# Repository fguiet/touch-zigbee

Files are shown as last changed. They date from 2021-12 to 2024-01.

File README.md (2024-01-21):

#  Touch-Zigbee

## Forewords

This project aims at creating a ultra low powered capacitive XBee enabled touch button.

It can be used to replace mechanical on/off switch to turn on/off a lamp for instance.

Mecanical swich should be me removed and wire connected so that the lamp is always ON.

Less than 10 uA is required to make this stuff work :)

__My Use case :__

I have got a Hue lamp in my office. 

Hue lamp can be switch off and on thank to the Philips Hue API.

So I am gonna replace the mecanical on/off swith by the Touch-Zigbee switch.

Here is the workflow:

Touch-Zigbee capacitive switch sends a message to a zigbee reveiver plugged in a Rapsberry.

A nodered flow will listen to the ZigBee messages and call the Philips Hue API to turn the Hue lamp on and off.

Obviously, the API or Nodered communicates with Home Assitant so I can see the Philips Hue Lamp status.

Moreover, I can programm some scenes when not at home to simulate that somebody is at home.

## Documentation

Here is some notes I took when I realized this project : [Project Notes](documentation/touch-zigbee.md)

## Illustrations

* Bare PCB received from JLCPCB and realized with KiCAD 5.1.12

Diameter : only 5 cm (can be insert in a standard French mecanical on/off switch case)

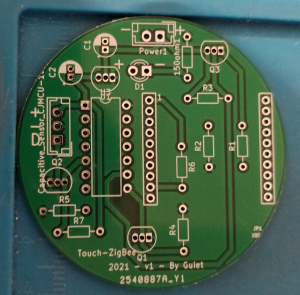
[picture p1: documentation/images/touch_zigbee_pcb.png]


* Assembled PCB 

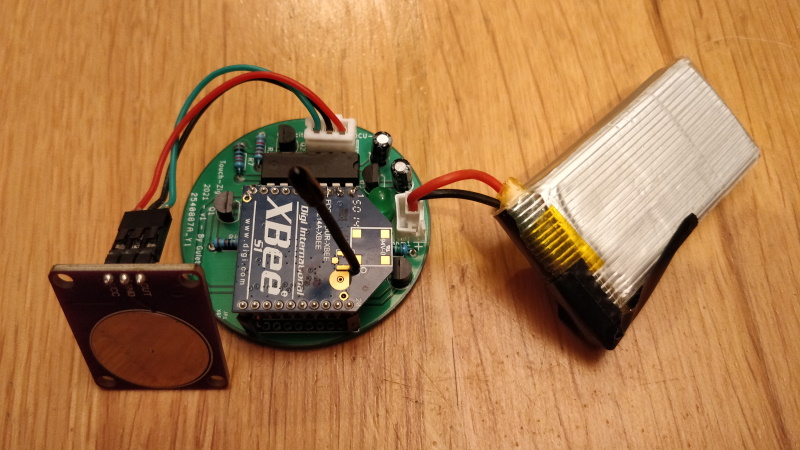
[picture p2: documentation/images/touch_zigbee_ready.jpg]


* Testing XBee communication with XCTU

NB : Version 2.0.0 of this project use XBee API Mode 2 (as you can see of the picture below I was using transparent mode before (AT))

Battery voltage can be read and send :) Nice

A led is blinking when the capacitive sensor is touched :)

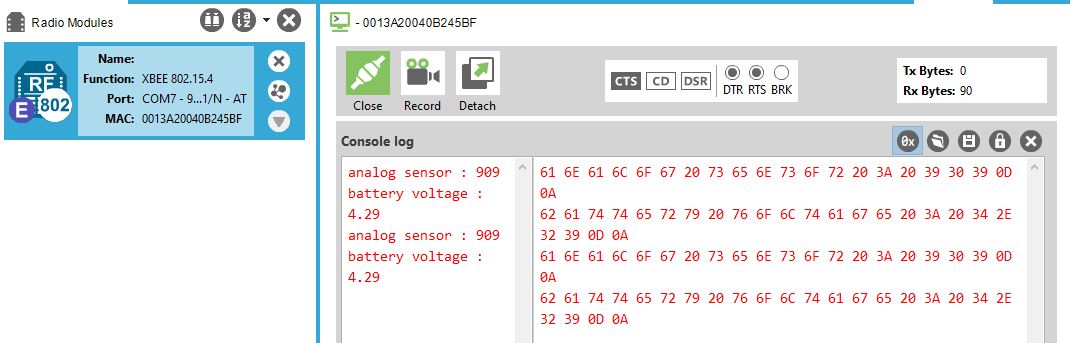
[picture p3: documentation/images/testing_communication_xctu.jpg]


* Wall plug design in FreeCAD

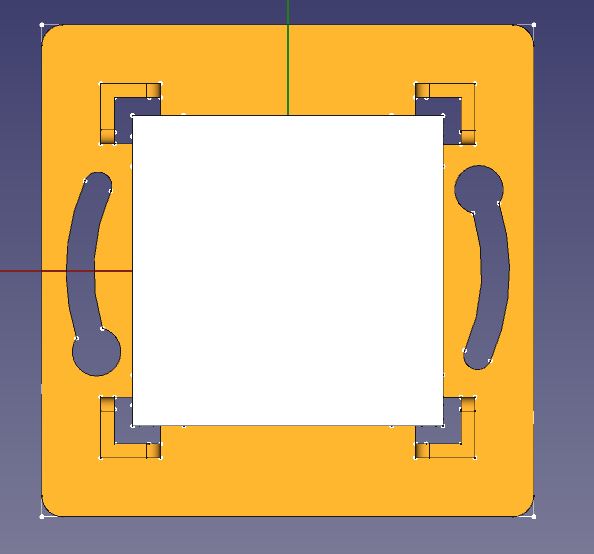
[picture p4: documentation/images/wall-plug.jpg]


* 3D Printing wallplug (not the last version)

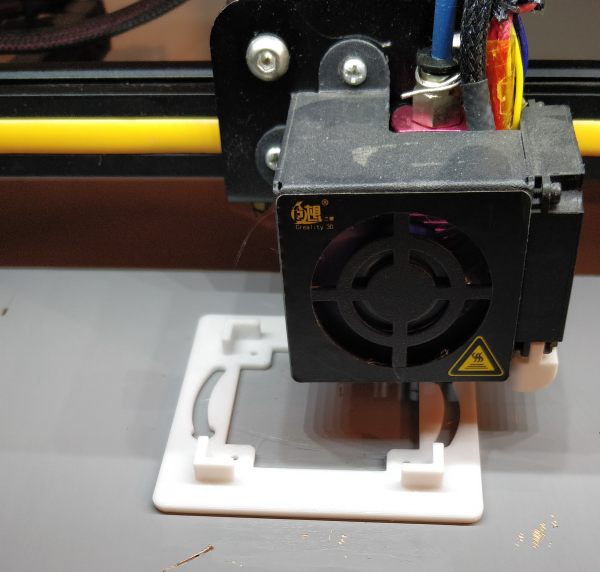
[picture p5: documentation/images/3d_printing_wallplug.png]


* Assembling the whole stuff (I do not have the XBee pin header at you can see, it is coming from China)

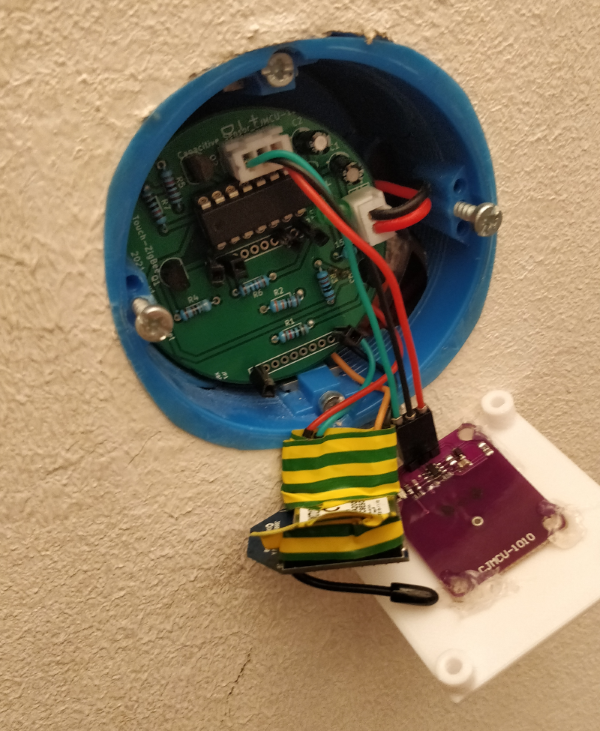
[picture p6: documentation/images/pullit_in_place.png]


* Everything in place (last version remove the little gaps)

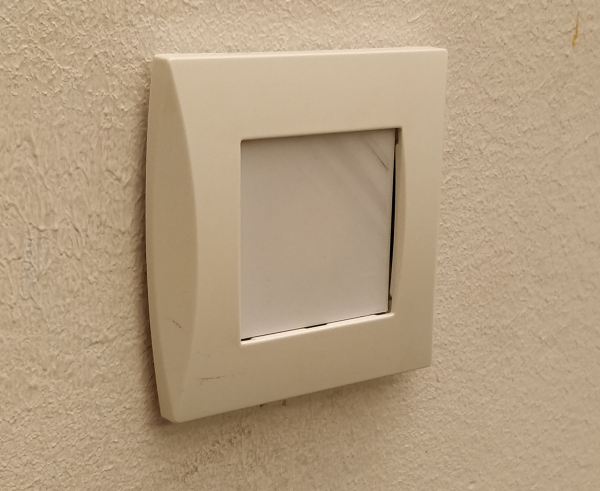
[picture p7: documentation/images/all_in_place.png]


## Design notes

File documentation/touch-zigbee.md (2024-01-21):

# Touch-Zigbee

## Consumption

* CMJMCU-1010 and 7333-LDO 

With tiny led that indicates power on is on

        Consumption : 1.2 mA (no touch)

        Consumption : 2.3 mA (touch + touch led indicator is on)

When tiny led with tiny led that indicates power on is removed

        Consumption : < 10uA (no touch)

        Consumption : around 1.2 mA (touch + touch led indicator is on)

* ATtiny 84 + green led and 150ohm reistor

        Consumption : 1.2 mA (green led off)

        Consumption : 8.5 mA (green led on)

* ATtiny 84 alone (sleep mode, no ADC)

        Consumption : 1.6uA

* ATtiny 84 + XBee (no sleep)

        Consumption : 52 mA

* ATtiny 84 + XBee (sleep)

        Consumption : around 4uA

* ATiny 84 (sleep mode) + XBee (sleepmode) + CMJMCU-1010

        Consumption : Peak at 20 uA when touching then less than 10 uA :)

## Configuring XBee S1 with XCTU v6.5.6

I am using old XBee S1

### XBee firmware update

Update the XBee firmware with last version using XCTU v6.5.6

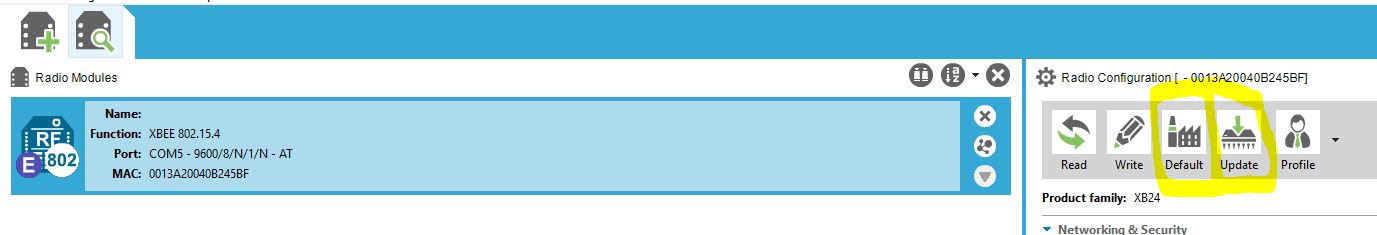
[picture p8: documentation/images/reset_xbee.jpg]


In my case as of 2021/11 :



To make the Xbee talks to each other just config them with the same Channel and PAN (Personnal Area Network ID). Messages will be broadcasted.



### XBee pinout

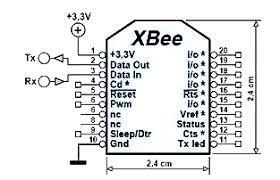
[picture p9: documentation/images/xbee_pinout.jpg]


### Sleep mode

To config the Xee to use the sleep mode, just change the sleep mode setting



Sleep mode will be control by pin 9, see <https://www.digi.com/resources/documentation/Digidocs/90001456-13/reference/r_wk_sleep_mode.htm>

PIN 9 HIGH : Xbee sleeps
PIN 9 DOWN : Xbee awake

### API Mode 

2024/01/21 - Quite a big change. I am using Xbee API with escaped mode instead of transparent mode (AT). So know I can have more information (like RSSI) and be compatible with my other projects.



## Read battery voltage

https://gist.github.com/dwhacks/7208805

## Pull up / pull down

Quick reminder if pullup/pulldown : <https://arduino.developpez.com/cahiers-pratiques/resistance-pullup-pulldown/>

## Interrupt and power saving stuffwith ATtiny 85

See <https://forum.arduino.cc/t/attiny84-sleep-issues/199824/8>
See <http://www.gammon.com.au/power>
See <https://www.marcelpost.com/wiki/index.php/ATtiny84_ADC>

Extract from ATtiny datasheet p49.

²> 9.2 External Interrupts
> Note that recognition of falling or rising edge interrupts on INT0 requires the presence of an
> I/O clock, as described in “Clock Sources” on page 25.

## Add SoftSerial to the Arduino IDE

From 2024/01/21, I moved to XBee API Mode. 
Firmware is now 2.0.0.
I had a hard time making XBee API Mode to work.

The libray I used up to know : SoftwareSerial was not capable of working at more than 9600 bauds...it took quite a long time to understand this problem.

So I tried to use the following library [ATtinySerialOut](https://github.com/ArminJo/ATtinySerialOut). 

But I soon realiazed that this library was not working with the PIN 7 (PA6).

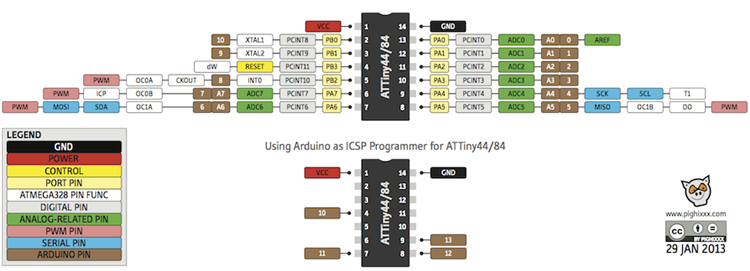
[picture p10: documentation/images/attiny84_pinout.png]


The only working pin was PB1 (PIN 3) or PB2 (PIN 5) at 38400 bauds.

This made me change the PCD Datasheet...I soldered a piece of wire to make it work for now...

To debug the serial port I used a serial to USB port adapter

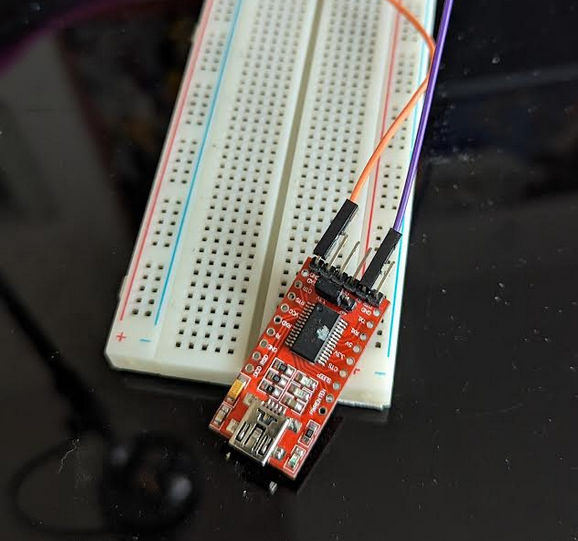
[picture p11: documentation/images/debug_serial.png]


GND to GND
PIN RX (serial adapter) to PA1 of ATtiny

Then I used `screen`

```bash
# Quit CTRL-A then :quit
screen /dev/ttyUSB0 38400
```

__Note below are deprecated from 2024/01/21 :__

I am using the SoftwareSerial that comes with the Arduino IDE : See <C:\Users\fguie\AppData\Local\Arduino15\packages\arduino\hardware\avr\1.8.3\libraries\SoftwareSerial>

It may be possible to use another one:

See : <https://github.com/shimniok/ATtinySoftSerial>

See <https://www.arduino.cc/en/guide/libraries>, Manual installation

1. Go to File, Preferences and get the sketchbook location
2. Copy the library to the libraries folder (in my case `C:\Users\fguie\Documents\Arduino\libraries`)

## Program the ATtiny XX (ATtiny 84 in my case) using Arduino IDE

See <https://github.com/damellis/attiny>
See <http://highlowtech.org/?p=1695>
See <http://highlowtech.org/?p=1706>

Arduino used as an ISP (In System Programmer)

1. Select the Arduino Uno Board, then upload ISP sketch to the Arduino
2. follow this wiring diagram : <https://www.instructables.com/Using-the-Arduino-Uno-to-program-ATTINY84-20PU/> or <https://42bots.com/tutorials/programming-attiny84-attiny44-with-arduino-uno/> (See image below)



Don't forget to set Programmer : Arduino As ISP and select the ATtiny 84 Board

To program:

VCC (3.3v ou 5V) <=> VCC (pin1)

GND <=> GND (pin14)

Arduino Pin 10 <=> RESET 

Arduino Pin 11 <=> pin7 (arduino pin 6)

Arduino Pin 12 <=> pin8 (arduino pin 5)

Arduino Pin 13 <=> pin9 (arduino pin 4)

## Kicad

__Schematic__

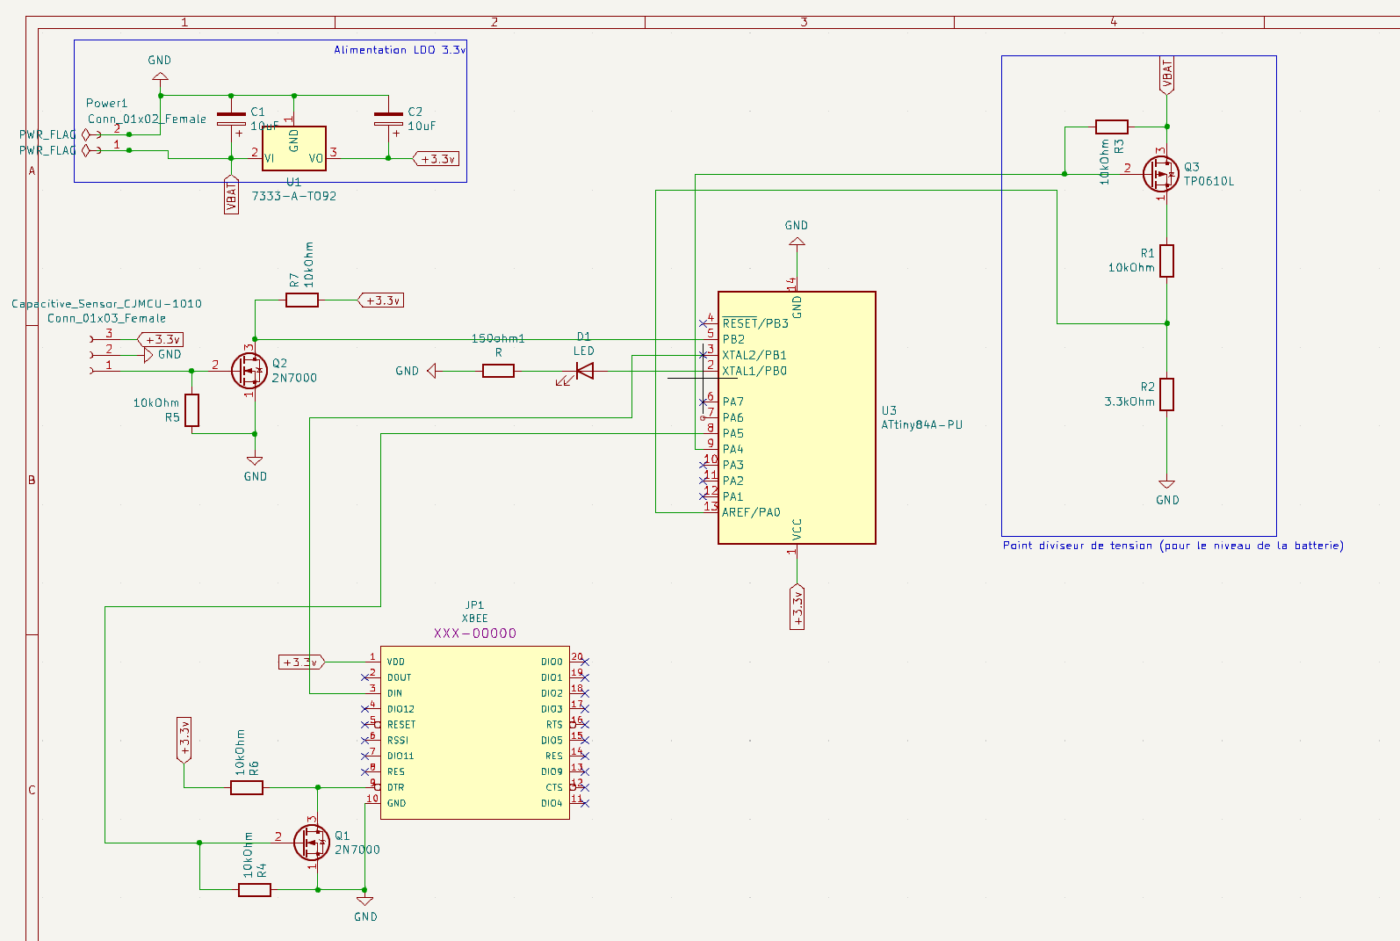
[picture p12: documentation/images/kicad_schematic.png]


Ce tuto : <https://www.youtube.com/watch?v=RpVIrzEUsIM&t=1837s>

__Grandes étapes__

1. Remplir le cartouche

Fichier, Ajustage page

2. Place all your components

Shortcut

M : Move
R : Rotate
Tab  : Pour bouger le composant avec les fils accrochés

3. Annotation de la schématique (pour numéroter les composants)

4. Assigner les empreintes des composants de la schématique

5. Génération de la net liste

6. Editeur de circuit imprimé et lecture de la net liste

7. Placement des composants

8. Couche Edge cut (contour de carte)

9. Routage

Couche F. Cu (Front en rouge couche du dessus)
Couche B. Cu (Front en vert couche du dessous)

Fichiers, Options CI, Classe d'Equipots, j'utilise 0.762 comme largeur de piste

Ne pas relier les GND, ca sera automatique avec le plan de masse

10 . Serigrafie avec couche Drawing User pour mettre les indications + - et autres

11 . Générer les fichiers Gerber, Fichier Tracer (ne pas oublier de générer le fichier de percage)

12 . Faire un Zip et envoyer sur JLCPCB par exemple

## References 

* [Communication XBee](https://www.redohm.fr/2015/03/communication-xbee/)
* [Configuration XBee](https://www.electro-info.ovh/configuration-d-un-module-XBEE-avec-XCTU)
* [Un programme qui ressemble a ce que je fais](https://github.com/cano64/ATTiny85-ATTiny84-BMP085-Arduino-Library-FastAltitude/issues/1)
* [How works a switch without neutral](https://www.youtube.com/watch?v=VNYcD7MEp4A)

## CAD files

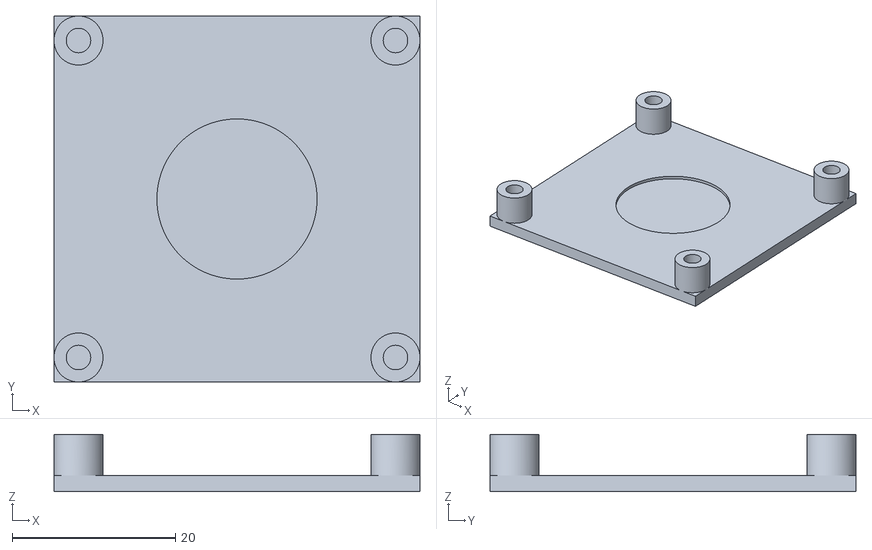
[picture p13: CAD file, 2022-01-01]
freecad/wallplug-wallplug-front-body.stl
44.8 x 44.8 x 7.00

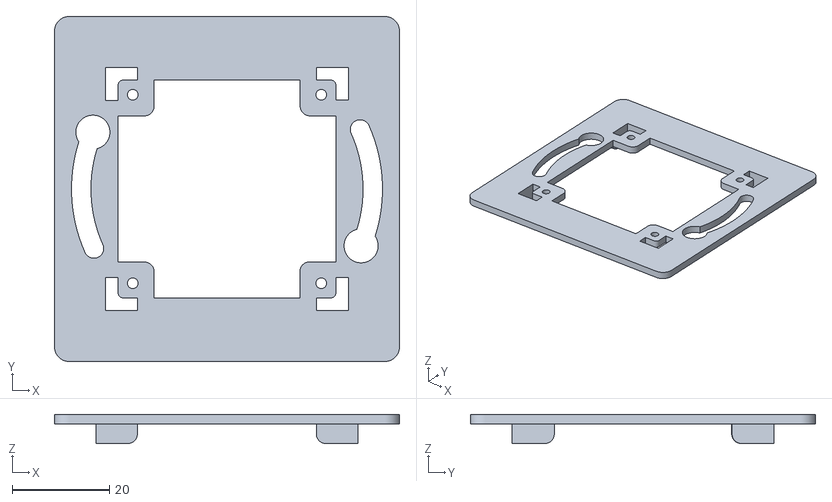
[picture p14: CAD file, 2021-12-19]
freecad/wallplug-wallplug-behind-body.stl
71.0 x 71.0 x 6.00

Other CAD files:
freecad/wallplug.FCStd

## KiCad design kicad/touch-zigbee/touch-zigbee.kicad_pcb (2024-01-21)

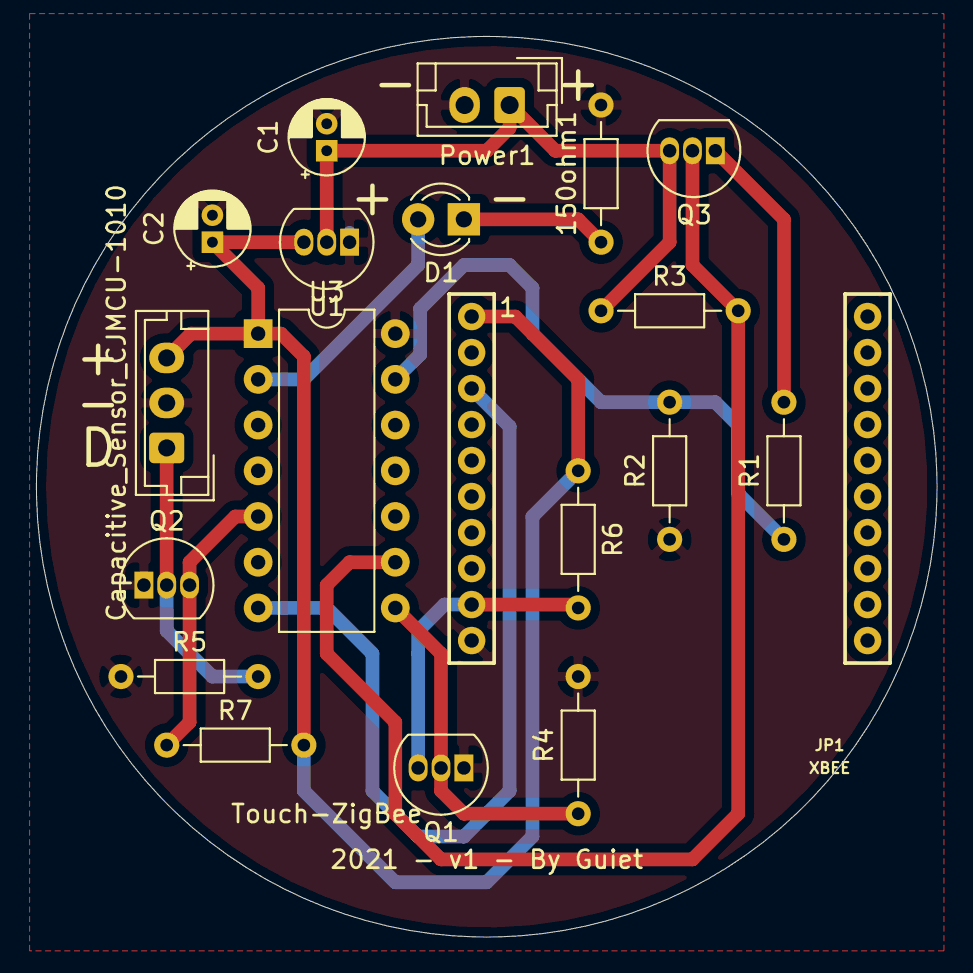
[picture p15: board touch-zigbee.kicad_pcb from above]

Board: 2 copper layers, 50.0 x 50.0 mm, 19 parts (0 on the bottom side), 13 nets.

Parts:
150ohm1: R; R_Axial_DIN0204_L3.6mm_D1.6mm_P7.62mm_Horizontal
C1, C2: 10uF; CP_Radial_D4.0mm_P1.50mm
Capacitive_Sensor_CJMCU-1010: Conn_01x03_Female; JST_EH_B3B-EH-A_1x03_P2.50mm_Vertical
D1: LED; LED_D3.0mm_IRBlack
JP1: XBEE
Power1: Conn_01x02_Female; JST_EH_B2B-EH-A_1x02_P2.50mm_Vertical
Q1, Q2: 2N7000; TO-92_Inline
Q3: TP0610L; TO-92L_Inline
R1, R3, R4, R5, R6, R7: 10kOhm; R_Axial_DIN0204_L3.6mm_D1.6mm_P7.62mm_Horizontal
R2: 3.3kOhm; R_Axial_DIN0204_L3.6mm_D1.6mm_P7.62mm_Horizontal
U1: 7333-A-TO92; TO-92_Inline
U3: ATtiny84A-PU; DIP-14_W7.62mm

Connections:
+3.3v: C2.1, Capacitive_Sensor_CJMCU-1010.3, JP1.1, R6.1, R7.2, U1.3, U3.1
GND: 150ohm1.2, C1.2, C2.2, Capacitive_Sensor_CJMCU-1010.2, JP1.10, Power1.2, Q1.1, Q2.1, R2.1, R4.2, R5.1, U1.1, U3.14
unnamed: 150ohm1.1, D1.1
unnamed: Capacitive_Sensor_CJMCU-1010.1, Q2.2, R5.2
unnamed: D1.2, U3.2
unnamed: JP1.3, U3.7
unnamed: JP1.9, Q1.3, R6.2
unnamed: Q1.2, R4.1, U3.8
unnamed: Q2.3, R7.1, U3.5
unnamed: Q3.1, R1.2
unnamed: Q3.2, R3.2, U3.9
unnamed: R1.1, R2.2, U3.13
VBAT: C1.1, Power1.1, Q3.3, R3.1, U1.2

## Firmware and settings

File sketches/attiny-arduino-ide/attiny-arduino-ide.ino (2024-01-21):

/*
 *  Touch-Zigbee project
 *  
 *  Description:
 *     
 *     This program uses interrupt to detect when the capacitive button is touched
 *     Then it wakes up the XBee and send a message
 *     The message is received on another XBee plugged in a Raspberry.
 *     A Nodered flow then toggle the Philipps Hue light bulb on and off depending on the current light bulb state.
 *     
 *     This is an ultra low power battery operated design. It consumes only 10uA when sleeping.
 *     
 *     More info here : https://github.com/fguiet/touch-zigbee
 *     
 *  Board used : Using board 'ATtinyX4' from platform in folder: C:\Users\fguie\AppData\Local\Arduino15\packages\attiny\hardware\avr\1.0.2   
 *               Using Arduino As ISP to program the ATtiny84
 *               Careful : Serial only work at Clock Internal 1Mhz (do not use Clock Internal 8Mhz)
 *     
 *
 *  History : 
 *     - 2021/12/19 - Creation date - Firware Version 1.0
 *     - 2024/01/21 - Replace use of SoftwareSerial library, use of ATtinySerialOut at 38400 bauds. 
 *                  - ATtinySerialOut consumes less memory and allow use of 38400 bauds. SoftwareSerial only works at 9600 bauds
 *                  - Change to XBee API Mode 2 instead of Transparent mode
 *                  - ATtinySerialOut must be connected to PIN PB1 = Physical PIN 3 otherwise it does not work (so PCB schematic has been changed as well)
 *                  - Firmware Version is now 2.0
 *  
 *  Version : 2.0
 *  
 */

#include <avr/sleep.h>

//Uncomment this line below if you want to use 38400 bauds instead of 115200 bauds
#define TINY_SERIAL_DO_NOT_USE_115200BAUD

//PIN PB1 = Physical PIN 3
#define TX_PIN 1

//Work only clock internal set to 1Mhz and with TX_PIN set to 2, baud is 38400 bauds
#include "ATtinySerialOut.hpp"  // Available as Arduino library "ATtinySerialOut"

// ATTIny84 
// Use Arduino Pin on the pinout 
const byte LED = 10;
const byte PIN_LINK_TO_INT_PIN=8;
const byte INT_PIN=0; //This is the interrupt number link to pin 8
const byte WAKE_XBEE=5;
const byte ADC_PIN=0; //Arduino pin 13
const byte ENABLE_BATTERY_V_READING=4;

//Hue light bulb
//Office = 2
const String SENSOR_ID="2";
const String FIRMWARE_VERSION="2.0.0";

const byte numReadings = 5;

// the setup routine runs once when you press reset:
void setup() {
  // Must be called once if pin is not set to output otherwise
  initTXPin();

  // initialize the digital pin as an output.
  pinMode(LED, OUTPUT); 
  pinMode(PIN_LINK_TO_INT_PIN, INPUT_PULLUP);  

  pinMode(ENABLE_BATTERY_V_READING, OUTPUT); 
  digitalWrite(ENABLE_BATTERY_V_READING,HIGH);
    
  pinMode(WAKE_XBEE, OUTPUT); 
  digitalWrite(WAKE_XBEE,LOW);
}

// Needed to compute ZigBee API 2 mode frame length
void computeMSB_LSB(uint16_t number, uint8_t &msb, uint8_t &lsb) {
    msb = (number >> 8) & 0xFF; // Shift right by 8 bits to get MSB
    lsb = number & 0xFF;        // Mask to get LSB
}

// See https://forum.arduino.cc/t/how-to-calculate-checksum-for-16bit-address-xbee-tx-frame/439001/4
uint8_t calculateChecksum(const uint8_t* data, size_t length) {  
  uint8_t checksum = 0;
  for (size_t i = 0; i < length; ++i) {
    //Serial.println(data[i],HEX);
    checksum += data[i];
  }  
  checksum &= 0xFF;        // low order 8 bits
  checksum = 0xFF - checksum; // subtract from 0xFF

  return  checksum;
}

//Create the ZigBee Mode API 2 - frame
//
//Using 0x00 - 64-bit Transmit Request (Deprecated one, should use 0x10 but I am using old XBee S1 (802.15.4 protocol stack)
//See https://www.digi.com/resources/documentation/Digidocs/90001477/reference/r_frame_0x00.htm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
void createAndSendZigBeeAPIFrame(String message) {
  
  //Gets an array of String : message
  byte messageArray[message.length()+1];
  message.getBytes(messageArray, message.length()+1);

  //Get messageArraySize
  int messageArraySize = sizeof(messageArray) / sizeof(messageArray[0]);
  
  //Declare array with needed space for message + need byte of frame
  uint8_t frame[14+sizeof(messageArray)]; 
  
  //Empty frame
  for (int i=0; i < sizeof(frame) / sizeof(frame[0]) -1; i++) {    
    frame[i] = 0;    
  }

  //Initialize Frame
  frame[0] = 0x7E; // Start delimiter
  //
  frame[1] = 0x00; // Length MSB (to be updated later)
  frame[2] = 0x00; // Length LSB (to be updated later)
  //
  frame[3] = 0x00; // Frame type ie 0x00 - Tx (Transmit) - Request: 64-bits address
  // 
  frame[4] = 0x42; // Frame ID 0x42 why not ;-)
  //
  // Desination address : here my coordinator 
  frame[5] = 0x00;
  frame[6] = 0x13;
  frame[7] = 0xA2;
  frame[8] = 0x00;
  frame[9] = 0x40;
  frame[10] = 0xB2;
  frame[11] = 0x45;
  frame[12] = 0xBF;
  //
  frame[13] = 0x00; // Options
  //
  // DATA      
  for (int i=0; i < messageArraySize-1; i++) { 
    //Serial.println("TOTO:"+String(messageArray[i], HEX));
    frame[14+i] = messageArray[i];    
  }
  //Checksum = all data except start + length (on non escaped data)
  //Start compute at frame+3 (ie frame type) to 11 (frame type to options + message size)
  frame[14+messageArraySize-1] = calculateChecksum(frame+3, 11+messageArraySize-1);

  //In API 2 mode, the length field does not include any escape character in the frame and the checksum is calculated with non-escaped data.  
  uint8_t msb, lsb;
  //Serial.println("Message Size = " + String(11+messageArraySize-1));
  computeMSB_LSB(11+messageArraySize-1, msb, lsb);  

  //Serial.print("MSB: 0x");
  //Serial.println(msb, HEX);

  //Serial.print("LSB: 0x");
  //Serial.println(lsb, HEX);

  //Set frame length
  frame[1] = msb;
  frame[2] = lsb;

  int j=1;
  //Compute number final arraylenght necessary with escaped characters needed
  for (int i=1; i < 14+messageArraySize; i++) {
    
    if (frame[i] == 0x7E 
     || frame[i] == 0x7D 
     || frame[i] == 0x13
     || frame[i] == 0x11)
      j++;
    
    j++;
  }

  //
  // DEBUG
  //
  /*Serial.println("DEBUT FRAME");
  for (int i=0; i < sizeof(frame); i++) {    
    Serial.print("0x" + String(frame[i], HEX) + " ");
  }
  Serial.println("FIN FRAME");
  return ;*/

  //Escape frame (all byte exept Start delimiter)
  uint8_t escapedFrame[j];

  //Start delimiter
  escapedFrame[0] = frame[0];
  j = 1;

  for (int i=1; i < 14+messageArraySize; i++) {
    
    if (frame[i] == 0x7E) {
      escapedFrame[j] = 0x7D;
      j++;
      escapedFrame[j] = 0x5E;      
      j++;
      continue;
    }

    if (frame[i] == 0x7D) {
      escapedFrame[j] = 0x7D;
      j++;
      escapedFrame[j] = 0x5D;      
      j++;
      continue;
    }

    if (frame[i] == 0x13) {
      escapedFrame[j] = 0x7D;
      j++;
      escapedFrame[j] = 0x33;      
      j++;
      continue;
    }

    if (frame[i] == 0x11) {
      escapedFrame[j] = 0x7D;
      j++;
      escapedFrame[j] = 0x31;      
      j++;
      continue;
    }
    
    //other case
    escapedFrame[j] = frame[i];
    j++;

  }
  //
  // DEBUG
  //
  /*Serial.println("DEBUT FRAME");
  for (int i=0; i < sizeof(escapedFrame); i++) {    
    Serial.print("0x" + String(escapedFrame[i], HEX) + " ");
  }
  Serial.println("FIN FRAME");*/

  //Send frame
  //Serial.write(escapedFrame);
  
  //char tt []= {0x7E, 0x00, 0x7D, 0x33, 0x00, 0x42, 0x00, 0x7D, 0x33, 0xA2, 0x00, 0x40, 0xB2, 0x45, 0xBF, 0x00, 0x66, 0x72, 0x65, 0x64, 0x65, 0x72, 0x69, 0x63, 0xCE};

  //WORKING
  /*char tt [] = {0x7e, 0x0, 0x2a, 0x0, 0x42, 0x0, 0x7d, 0x33, 0xa2, 0x0, 0x40, 0xb2, 0x45, 0xbf, 0x0, 0x7b, 0x22, 0x74, 0x69, 0x70, 0x22, 0x3a, 0x22, 0x74, 0x72, 0x75, 0x65, 0x22, 0x2c, 0x22, 0x62, 0x61, 0x74, 0x74, 0x65, 0x72, 0x79, 0x22, 0x3a, 0x22, 0x32, 0x2e, 0x34, 0x32, 0x22, 0x7d, 0x5d, 0x9c};
  for (int i=0;i<sizeof(tt);i++) {
    Serial.print((char)tt[i]);    
  }*/

  //XBee.flush();

  //uint8_t tt []= {0x7E, 0x00, 0x7D, 0x33, 0x00, 0x42, 0x00, 0x7D, 0x33, 0xA2, 0x00, 0x40, 0xB2, 0x45, 0xBF, 0x00, 0x66, 0x72, 0x65, 0x64, 0x65, 0x72, 0x69, 0x63, 0xCE};
  //char* ptr = escapedFrame;
  //Serial.print(tt);

  for (int i=0;i<sizeof(escapedFrame);i++) {
    Serial.print((char)escapedFrame[i]);    
  }

  //Serial.flush();
}

float averageVoltage() {

  analogReference(INTERNAL);    // set the ADC reference to 1.1V
  
  int total = 0;
  
  digitalWrite(ENABLE_BATTERY_V_READING, LOW);
  
  for(byte i=0;i<numReadings;i++) {
    total = total + analogRead(ADC_PIN);
  }
  
  digitalWrite(ENABLE_BATTERY_V_READING, HIGH);
  
  int averageSensor = total / numReadings; 
  //test = averageSensor;
  
  //XBee.print("analog sensor : ");
  //XBee.println(averageSensor);

  //with R1 = 10kOhm, R2 = 3.3kOhm
  //Max voltage 4.2v of fully charged battery produces = 1.042 on A0
  //According to voltage divider formula : Vout = Vin * (R2 / (R1 + R2))

  //So 4.2v is roughly represented by 992 value on A0
  
  float voltage = (averageSensor * 4.28) / 992;
  
  return voltage;           
}

// the loop routine runs over and over again forever:
void loop() {

  attachInterrupt(INT_PIN, blink, LOW);
  
  //Go to sleep
  sleep_function();
  
  detachInterrupt(INT_PIN);   

  //Wake up XBee
  digitalWrite(WAKE_XBEE,HIGH);

  delay(50);

  float battery_voltage = averageVoltage();

  //Send XBee message  
  //XBee.print("fred");
  //XBee.println(String(battery_voltage,2));

 // XBee.print("{\"hue_id\":\"1\",\"battery\":\"" + String(battery_voltage,2) + "\",\"adc\":\""+String(test)+"\"}");
  // Serial.print("{\"hue_id\":"+String(SENSOR_ID)+",\"battery\":\"" + String(battery_voltage,2) + "\",\"fw\":\""+FIRMWARE_VERSION+"\"}");
  String message = "{\"id\":\""+SENSOR_ID+"\",\"bat\":\"" + String(battery_voltage,2) + "\",\"fw\":\""+FIRMWARE_VERSION+"\"}";
  //String message = "frederic";
  createAndSendZigBeeAPIFrame(message);

  //DEBUG WORKS
  /*
  char tt [] = {0x7e, 0x0, 0x2a, 0x0, 0x42, 0x0, 0x7d, 0x33, 0xa2, 0x0, 0x40, 0xb2, 0x45, 0xbf, 0x0, 0x7b, 0x22, 0x74, 0x69, 0x70, 0x22, 0x3a, 0x22, 0x74, 0x72, 0x75, 0x65, 0x22, 0x2c, 0x22, 0x62, 0x61, 0x74, 0x74, 0x65, 0x72, 0x79, 0x22, 0x3a, 0x22, 0x32, 0x2e, 0x34, 0x32, 0x22, 0x7d, 0x5d, 0x9c};
  for (int i=0;i<sizeof(tt);i++) {
    Serial.print((char)tt[i]);    
  }
  */
  
  //wait for message to be sent
  delay(100);

  //Go to sleep XBee
  digitalWrite(WAKE_XBEE,LOW);  
}

void blink() {
  digitalWrite(LED, HIGH);   // turn the LED on (HIGH is the voltage level)
  delay(500);               // wait for a second
  digitalWrite(LED, LOW);    // turn the LED off by making the voltage LOW
  delay(500);               // wait for a second
}

void sleep_function()
{ 
   
  // disable ADC
  ADCSRA &= ~_BV(ADEN);                   // ADC off
  
  set_sleep_mode(SLEEP_MODE_PWR_DOWN);//set deep sleep mode
  sleep_enable(); //enable sleep
  sleep_mode(); //start sleep
  sleep_disable(); //code continues here after wake up  

  // enable ADC
  ADCSRA |= _BV(ADEN);                    // ADC on
}

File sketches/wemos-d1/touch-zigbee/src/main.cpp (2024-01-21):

#include <Arduino.h>
#include <SoftwareSerial.h>

// D1 Pinout - https://randomnerdtutorials.com/esp8266-pinout-reference-gpios/

//RX=GPIO5=D5 (but it is D1 on silk screen)
//TX=GPIO4=D4 (but it is D2 on silk screen)
//Only TX will be used here
SoftwareSerial XBee (D5,D4);


void setup() {
  //Must be the same than Serial interface configured in XCTU
  XBee.begin(9600);
  Serial.begin(9600);
}

void loop() {

  XBee.println("Bonjour");
  Serial.println("Bonjour");
  delay(1000);
}

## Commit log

2021-12-18 Add freecad plug wall design and add some illustrations
    [wallplug-wallplug-behind-body.stl, wallplug-wallplug-front-body.stl, wallplug.FCStd]
2021-12-19 Minor modification to freecad and program code
    [wallplug-wallplug-behind-body.stl, wallplug.FCStd]
2022-01-01 add reference
    [wallplug-wallplug-front-body.stl, wallplug.FCStd]
2024-01-21 Move to Xbee API Mode 2, update doc, update kicad schematic
    [touch-zigbee-B_Cu.gbr, touch-zigbee-B_Mask.gbr, touch-zigbee-B_Paste.gbr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]
2024-01-21 update kicad schematic
    [touch-zigbee.kicad_sch]
